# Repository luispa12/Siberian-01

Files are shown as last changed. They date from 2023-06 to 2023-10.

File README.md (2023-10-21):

test

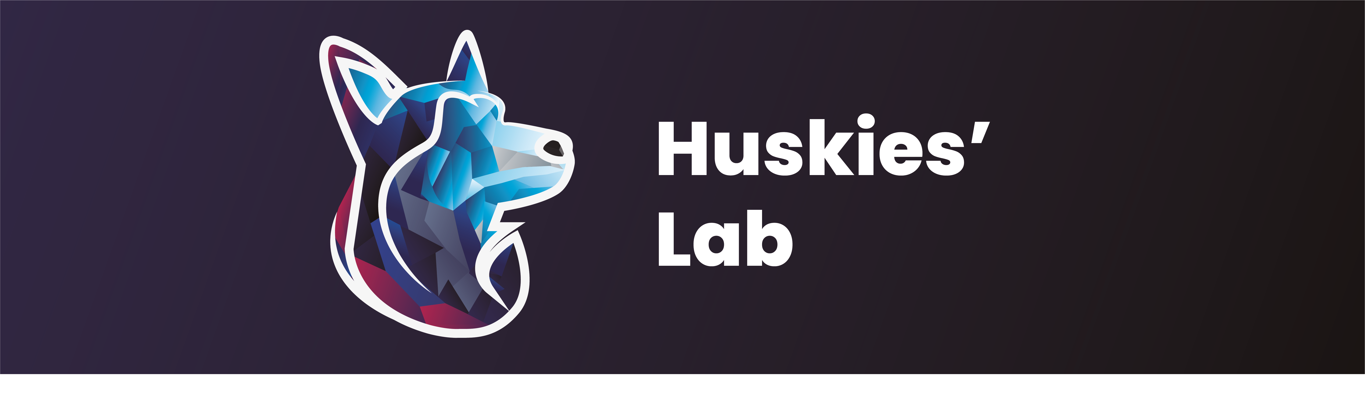
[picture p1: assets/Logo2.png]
Huskies' lab


## Project Specification

[Link to the Github repository](https://github.com/luispa12/Siberian-01)

This board is based on the RP2040 microcontroller from the Raspberry Foundation. 

It is a development board with the minimun requirements for the RP2040 IC to properly works, it complies with the USB 2.0 protocol, full use of all the GPIO pins, on board linear regulator for the 3.3V, 1 led status and another led connected to pin GPIO17.

It was designed with the purpose to learn how to design, assemble, document and manufacture (JLCPCB) printed circuit boarda (PCB's).   

### SoC Features

* Dual ARM Cortex-M0+ @ 133MHz
* 264kB on-chip SRAM in six independent banks
* Support for up to 16MB of off-chip Flash memory via dedicated QSPI bus
* DMA controller
* Fully-connected AHB crossbar
* Interpolator and integer divider peripherals
* On-chip programmable LDO to generate core voltage
* 2 on-chip PLLs to generate USB and core clocks
* 30 GPIO pins, 4 of which can be used as analog inputs
* Peripherals:
   * 2 UARTs
   * 2 SPI controllers
   * 2 I2C controllers
   * 16 PWM channels
   * USB 1.1 controller and PHY, with host and device support
   * 8 PIO state machines

For the complete description of the microcontroller, see the [RP2040 DATASHEET](https://datasheets.raspberrypi.com/rp2040/rp2040-datasheet.pdf).

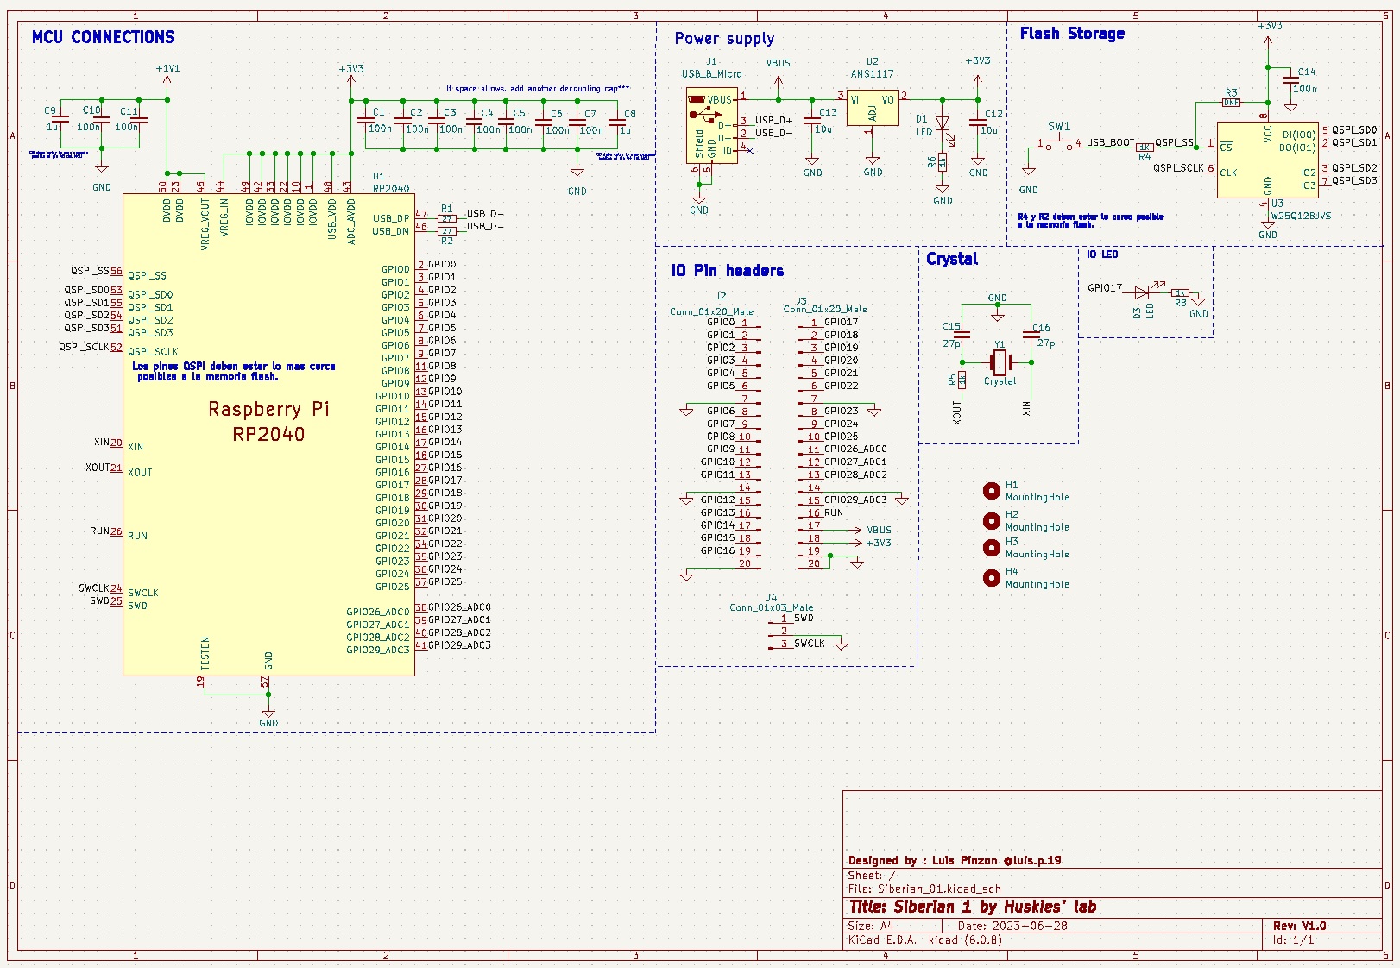
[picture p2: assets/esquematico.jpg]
Diagram


### Power

* USB Type B

#### Debug Pinout Connection 

| Pin number | SoC | Description |
|---|---|--- |
| 1 | 25 | SWD |
| 2 | -- | GND |
| 3 | 24 | SWCLK |

### Pin Layout

Pin Layou pending...

#### Left Side

| Pin number | SoC | Description |
|---|---|--- |
| 1 | 2 | GPIO0, SPI0 RX, UART0 TX, I2C0 SDA. |
| 2 | 3 | GPIO1, SPI0 CSn, UART0 RX, I2C0 SCL. |
| 3 | 4 | GPIO2, SPI0 SCK, UART0 CTS, I2C1 SDA. |
| 4 | 5 | GPIO3, SPI0 TX, UART0 RTS, I2C1 SCL. |
| 5 | 6 | GPIO4, SPI0 RX, UART1 TX, I2C0 SDA. |
| 6 | 7 | GPIO5, SPI0 CSn, UART1 RX, I2C0 SCL. |
| 7 | -- | GND. |
| 8 | 8 | GPIO6, SPI0 SCK, UART1 CTS, I2C1 SDA. |
| 9 | 9 | GPIO7, SPI0 TX, UART1 RTS, I2C1 SCL. |
| 10 | 11 | GPIO8, SPI1 RX, UART1 TX, I2C0 SDA. |
| 11 | 12 | GPIO9, SPI1 CSn, UART1 RX, I2C0 SCL. |
| 12 | 13 | GPIO10, SPI1 SCK UART1 CTS I2C1 SDA. |
| 13 | 14 | GPIO11, SPI1 TX UART1 RTS I2C1 SCL. |
| 14 | -- | GND. |
| 15 | 15 | GPIO12, SPI1 RX, UART0 TX, I2C0 SDA. |
| 16 | 16 | GPIO13, SPI1 CSn, UART0 RX, I2C0 SCL. |
| 17 | 17 | GPIO14, SPI1 SCK, UART0 CTS, I2C1 SDA. |
| 18 | 18 | GPIO15, SPI1 TX, UART0 RTS, I2C1 SCL. |
| 19 | 27 | GPIO16, SPI0 RX, UART0 TX, I2C0 SDA. |
| 20 | -- | GND. |

#### Right Side

| Pin number | SoC | Description |
|---|---|--- |
| 21 | 28 | GPIO17, SPI0 CSn, UART0 RX, I2C0 SCL. |
| 22 | 29 | GPIO18, SPI0 SCK, UART0 CTS, I2C1 SDA. |
| 23 | 30 | GPIO19, SPI0 TX, UART0 RTS, I2C1 SCL. |
| 24 | 31 | GPIO20, SPI0 RX, UART1 TX, I2C0 SDA, CLOCK GPIN0.  |
| 25 | 32 | GPIO21, SPI0 CSn, UART1 RX, I2C0 SCL, CLOCK GPOUT0.|
| 26 | 34 | GPIO22, SPI0 SCK, UART1 CTS, I2C1 SDA,CLOCK GPIN1. |
| 27 | -- | GND. |
| 28 | 35 | GPIO23, SPI0 TX, UART1 RTS, I2C1 SCL, CLOCK GPOUT1.|
| 29 | 36 | GPIO24, SPI1 RX, UART1 TX, I2C0 SDA,  CLOCK GPOUT2.|
| 30 | 36 | GPIO25, SPI1 CSn, UART1 RX, I2C0 SCL, CLOCK GPOUT3.|
| 31 | 38 | GPIO26\_ADC0, SPI1 SCK, UART1 CTS, I2C1 SDA. |
| 32 | 39 | GPIO27\_ADC1, SPI1 TX, UART1 RTS, I2C1 SCL. |
| 33 | 40 | GPIO28\_ADC2, SPI1 RX, UART0 TX, I2C0 SDA. |
| 34 | -- | GND. |
| 35 | 41 | GPIO29\_ADC3,SPI1 CSn, UART0 RX, I2C0 SCL. |
| 36 | 26 | RUN |
| 37 | -- | VBUS |
| 38 | -- | +3V3 |
| 39 | -- | GND. |
| 40 | -- | GND. |

| Function | SoC | 
|--- |--- |
| SPIx. | Connect one of the internal PL022 SPI peripherals to GPIO. | 
| UARTx. | Connect one of the internal PL011 UART peripherals to GPIO.|
| I2Cx. | Connect one of the internal DW I2C peripherals to GPIO. | 
| CLOCK GPINx. | General purpose clock inputs. Can be routed to a number of internal clock domains on RP2040, e.g. to provide a 1Hz clock for the RTC, or can be connected to an internal frequency counter.  | 
| CLOCK GPOUTx.| General purpose clock outputs. Can drive a number of internal clocks (including PLLoutputs) onto GPIOs, with optional integer divide.|

## Board Design

Top

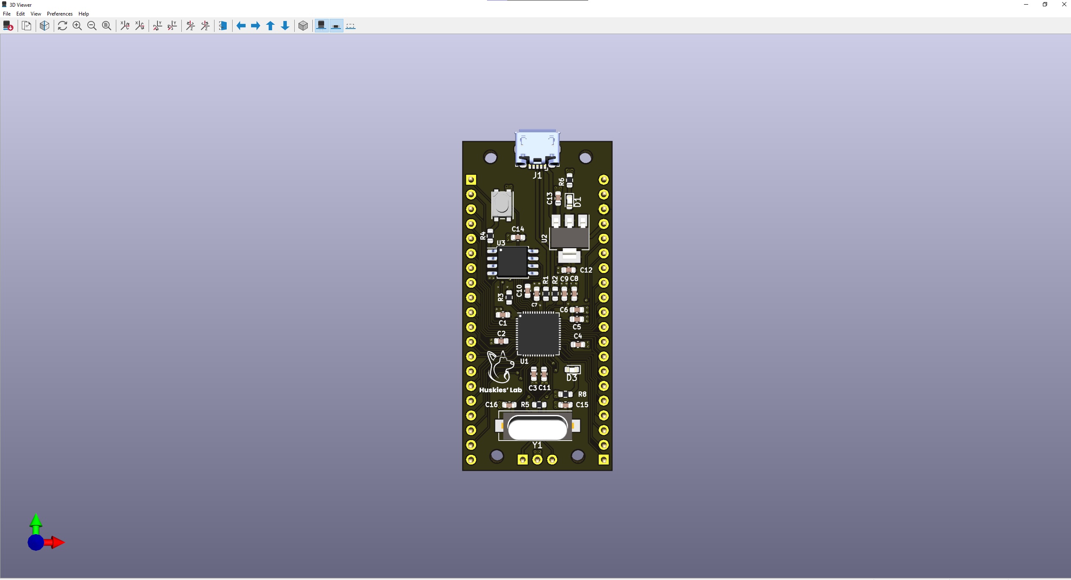
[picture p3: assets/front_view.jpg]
TOP


Bottom

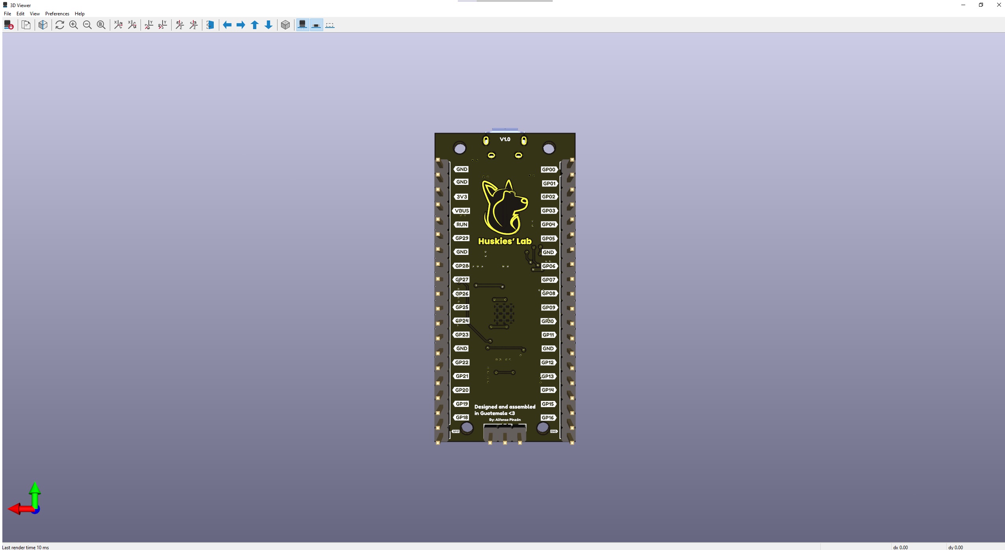
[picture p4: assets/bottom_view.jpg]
BOT


## Bill of Material

[Interactive BOM](docs/bom/bom.html)

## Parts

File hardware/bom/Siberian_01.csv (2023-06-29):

Source: | C:\Users\lapf9\OneDrive\Escritorio\huskies labs designs\Siberian_01\hardware\Siberian_01.kicad_sch
Date: | 6/28/2023 10:44:40 PM
Tool: | Eeschema (6.0.8)
Generator: | D:\kicad\6.0\bin\scripting\plugins/bom_csv_grouped_by_value_with_fp.py
Component Count: | 38
Ref | Qnty | Value | Cmp name | Footprint | Description | Vendor
C1, C2, C3, C4, C5, C6, C7, C10, C11, C14, | 10 | 100n | C_Small | Capacitor_SMD:C_0603_1608Metric | Unpolarized capacitor, small symbol
C8, C9, | 2 | 1u | C_Small | Capacitor_SMD:C_0603_1608Metric | Unpolarized capacitor, small symbol
C12, C13, | 2 | 10u | C_Small | Capacitor_SMD:C_0603_1608Metric | Unpolarized capacitor, small symbol
C15, C16, | 2 | 27p | C_Small | Capacitor_SMD:C_0603_1608Metric | Unpolarized capacitor, small symbol
D1, D3, | 2 | LED | LED | LED_SMD:LED_0603_1608Metric | Light emitting diode
H1, H2, H3, H4, | 4 | MountingHole | MountingHole | MountingHole:MountingHole_2.1mm | Mounting Hole without connection
J1, | 1 | USB_B_Micro | USB_B_Micro | Connector_USB:USB_Micro-B_Amphenol_10118194_Horizontal | USB Micro Type B connector
J2, J3, | 2 | Conn_01x20_Male | Conn_01x20_Male | Connector_PinHeader_2.54mm:PinHeader_1x20_P2.54mm_Vertical | Generic connector, single row, 01x20, script generated (kicad-library-utils/schlib/autogen/connector/)
J4, | 1 | Conn_01x03_Male | Conn_01x03_Male | Connector_PinHeader_2.54mm:PinHeader_1x03_P2.54mm_Vertical | Generic connector, single row, 01x03, script generated (kicad-library-utils/schlib/autogen/connector/)
R1, | 1 | 27 | R_Small | Resistor_SMD:R_0603_1608Metric | Resistor, small symbol
R2, | 1 | 27 | R_Small | Resistor_SMD:R_0603_1608Metric | Resistor, small symbol
R3, | 1 | DNF | R_Small | Resistor_SMD:R_0603_1608Metric | Resistor, small symbol
R4, | 1 | 1K | R_Small | Resistor_SMD:R_0603_1608Metric | Resistor, small symbol
R5, R6, R8, | 3 | 1k | R_Small | Resistor_SMD:R_0603_1608Metric | Resistor, small symbol
SW1, | 1 | PTS815_SJM_250_SMTR_LFS | PTS815_SJM_250_SMTR_LFS | FOOTPRINTS_s1:SW4_PTS815 SJM 250 SMTR LFS_CNK
U1, | 1 | RP2040 | RP2040 | MCU_RaspberryPi_and_Boards:RP2040-QFN-56
U2, | 1 | AMS1117 | AMS1117 | Package_TO_SOT_SMD:SOT-223-3_TabPin2 | 1A Low Dropout regulator, positive, adjustable output, SOT-223
U3, | 1 | W25Q128JVS | W25Q128JVS | Package_SO:SOIC-8_5.23x5.23mm_P1.27mm | 128Mb Serial Flash Memory, Standard/Dual/Quad SPI, SOIC-8
Y1, | 1 | Crystal | Crystal | MCU_RaspberryPi_and_Boards:Crystal_SMD_HC49-US | Two pin crystal

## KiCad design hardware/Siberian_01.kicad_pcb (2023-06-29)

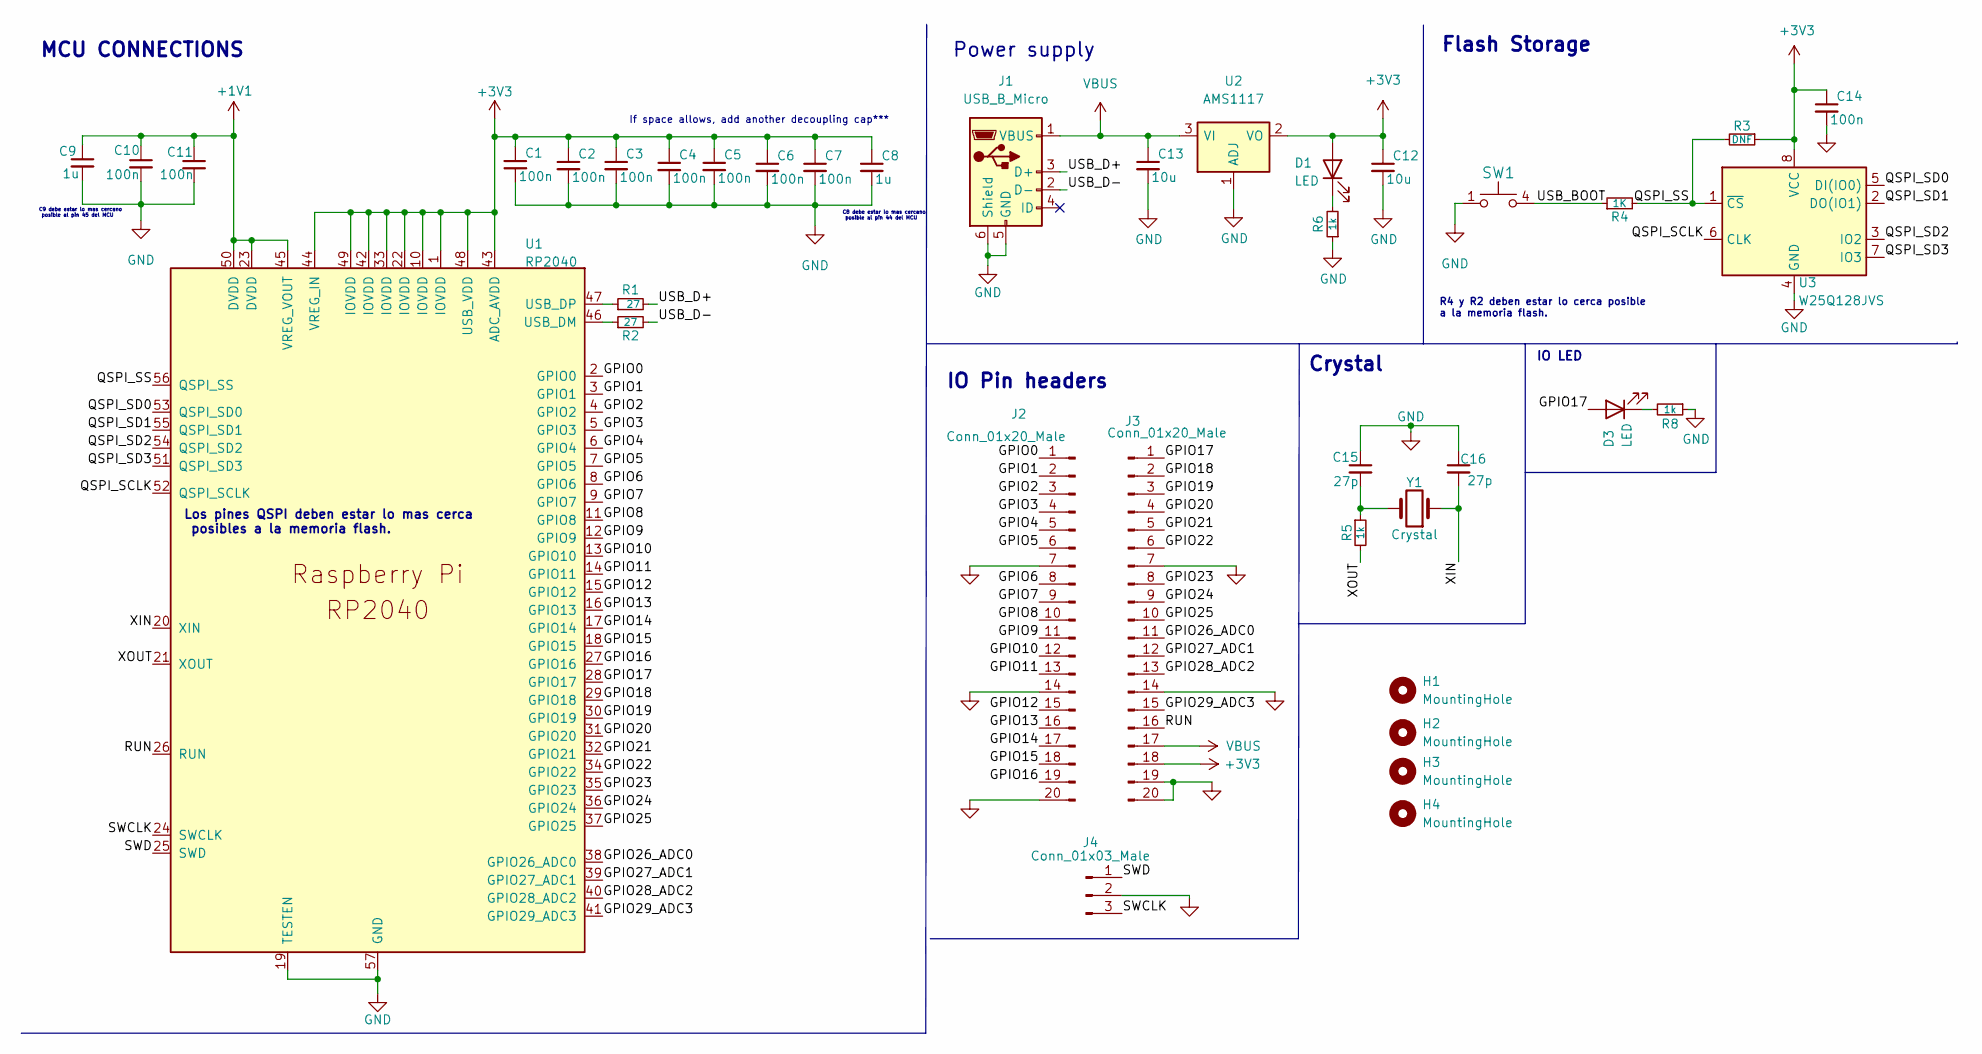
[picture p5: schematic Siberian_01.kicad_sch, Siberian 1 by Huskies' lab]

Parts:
C1, C2, C3, C4, C5, C6, C7, C10, C11, C14: 100n; C_0603_1608Metric
C8, C9: 1u; C_0603_1608Metric
C12, C13: 10u; C_0603_1608Metric
C15, C16: 27p; C_0603_1608Metric
D1, D3: LED; LED_0603_1608Metric
H1, H2, H3, H4: MountingHole; MountingHole_2.1mm
J1: USB_B_Micro; USB_Micro-B_Amphenol_10118194_Horizontal
J2, J3: Conn_01x20_Male; PinHeader_1x20_P2.54mm_Vertical
J4: Conn_01x03_Male; PinHeader_1x03_P2.54mm_Vertical
R1, R2: 27; R_0603_1608Metric
R3: DNF; R_0603_1608Metric
R4: 1K; R_0603_1608Metric
R5, R6, R8: 1k; R_0603_1608Metric
SW1: PTS815_SJM_250_SMTR_LFS; SW4_PTS815 SJM 250 SMTR LFS_CNK
U1: RP2040; RP2040-QFN-56
U2: AMS1117; SOT-223-3_TabPin2
U3: W25Q128JVS; SOIC-8_5.23x5.23mm_P1.27mm
Y1: Crystal; Crystal_SMD_HC49-US

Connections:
+1V1: C9.1, C10.1, C11.1, U1.23 (DVDD), U1.45 (VREG_VOUT), U1.50 (DVDD)
+3V3: C1.1, C2.1, C3.1, C4.1, C5.1, C6.1, C7.1, C8.1, C12.1, C14.1, D1.2 (A), J3.18, R3.1, U1.1 (IOVDD), U1.10 (IOVDD), U1.22 (IOVDD), U1.33 (IOVDD), U1.42 (IOVDD), U1.43 (ADC_AVDD), U1.44 (VREG_IN), U1.48 (USB_VDD), U1.49 (IOVDD), U2.2 (VO), U3.8 (VCC)
/GPIO0: J2.1, U1.2 (GPIO0)
/GPIO1: J2.2, U1.3 (GPIO1)
/GPIO2: J2.3, U1.4 (GPIO2)
/GPIO3: J2.4, U1.5 (GPIO3)
/GPIO4: J2.5, U1.6 (GPIO4)
/GPIO5: J2.6, U1.7 (GPIO5)
/GPIO6: J2.8, U1.8 (GPIO6)
/GPIO7: J2.9, U1.9 (GPIO7)
/GPIO8: J2.10, U1.11 (GPIO8)
/GPIO9: J2.11, U1.12 (GPIO9)
/GPIO10: J2.12, U1.13 (GPIO10)
/GPIO11: J2.13, U1.14 (GPIO11)
/GPIO12: J2.15, U1.15 (GPIO12)
/GPIO13: J2.16, U1.16 (GPIO13)
/GPIO14: J2.17, U1.17 (GPIO14)
/GPIO15: J2.18, U1.18 (GPIO15)
/GPIO16: J2.19, U1.27 (GPIO16)
/GPIO17: D3.2 (A), J3.1, U1.28 (GPIO17)
/GPIO18: J3.2, U1.29 (GPIO18)
/GPIO19: J3.3, U1.30 (GPIO19)
/GPIO20: J3.4, U1.31 (GPIO20)
/GPIO21: J3.5, U1.32 (GPIO21)
/GPIO22: J3.6, U1.34 (GPIO22)
/GPIO23: J3.8, U1.35 (GPIO23)
/GPIO24: J3.9, U1.36 (GPIO24)
/GPIO25: J3.10, U1.37 (GPIO25)
/GPIO26_ADC0: J3.11, U1.38 (GPIO26_ADC0)
/GPIO27_ADC1: J3.12, U1.39 (GPIO27_ADC1)
/GPIO28_ADC2: J3.13, U1.40 (GPIO28_ADC2)
/GPIO29_ADC3: J3.15, U1.41 (GPIO29_ADC3)
/QSPI_SCLK: U1.52 (QSPI_SCLK), U3.6 (CLK)
/QSPI_SD0: U1.53 (QSPI_SD0), U3.5 (DI(IO0))
/QSPI_SD1: U1.55 (QSPI_SD1), U3.2 (DO(IO1))
/QSPI_SD2: U1.54 (QSPI_SD2), U3.3 (IO2)
/QSPI_SD3: U1.51 (QSPI_SD3), U3.7 (IO3)
/QSPI_SS: R3.2, R4.2, U1.56 (QSPI_SS), U3.1 (~CS)
/RUN: J3.16, U1.26 (RUN)
/SWCLK: J4.3, U1.24 (SWCLK)
/SWD: J4.1, U1.25 (SWD)
/USB_BOOT: R4.1, SW1.4
/USB_D+: J1.3 (D+), R1.2
/USB_D-: J1.2 (D-), R2.2
/XIN: C16.2, U1.20 (XIN), Y1.1
/XOUT: R5.2, U1.21 (XOUT)
GND: C1.2, C2.2, C3.2, C4.2, C5.2, C6.2, C7.2, C8.2, C9.2, C10.2, C11.2, C12.2, C13.2, C14.2, C15.1, C16.1, J1.5 (GND), J1.6 (Shield), J2.7, J2.14, J2.20, J3.7, J3.14, J3.19, J3.20, J4.2, R6.1, R8.1, SW1.1, U1.19 (TESTEN), U1.57 (GND), U2.1 (ADJ), U3.4 (GND)
unnamed: C15.2, R5.1, Y1.2
unnamed: D1.1 (K), R6.2
unnamed: D3.1 (K), R8.2
unnamed: R1.1, U1.47 (USB_DP)
unnamed: R2.1, U1.46 (USB_DM)
VBUS: C13.1, J1.1 (VBUS), J3.17, U2.3 (VI)

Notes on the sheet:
Los pines QSPI deben estar lo mas cerca posibles a la memoria flash.
MCU CONNECTIONS
C8 debe estar lo mas cercano posible al pin 44 del MCU
R4 y R2 deben estar lo cerca posible a la memoria flash.
If space allows, add another decoupling cap***
Power supply
IO LED
C9 debe estar lo mas cercano posible al pin 45 del MCU
IO Pin headers
Flash Storage
Crystal

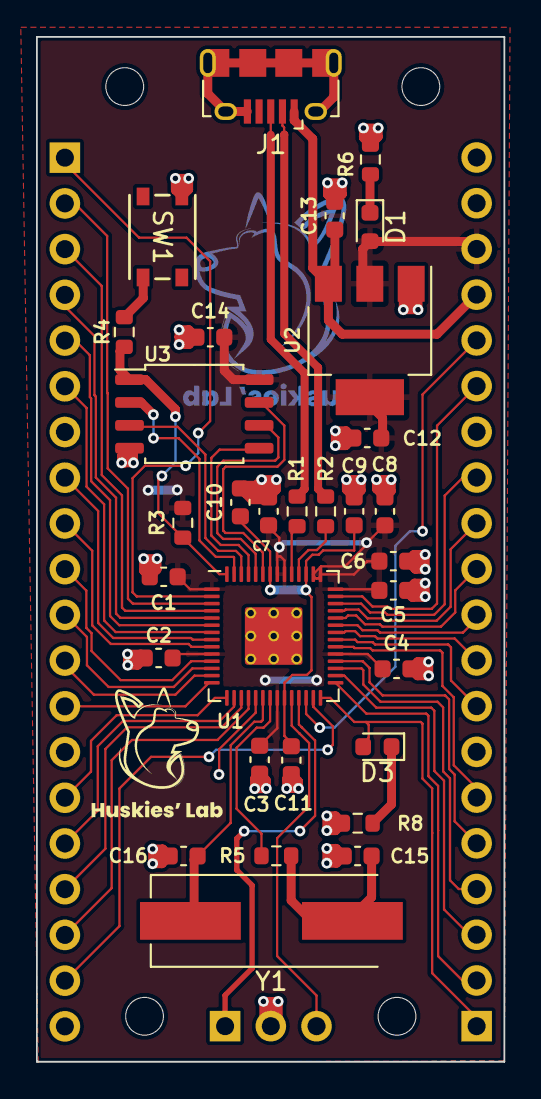
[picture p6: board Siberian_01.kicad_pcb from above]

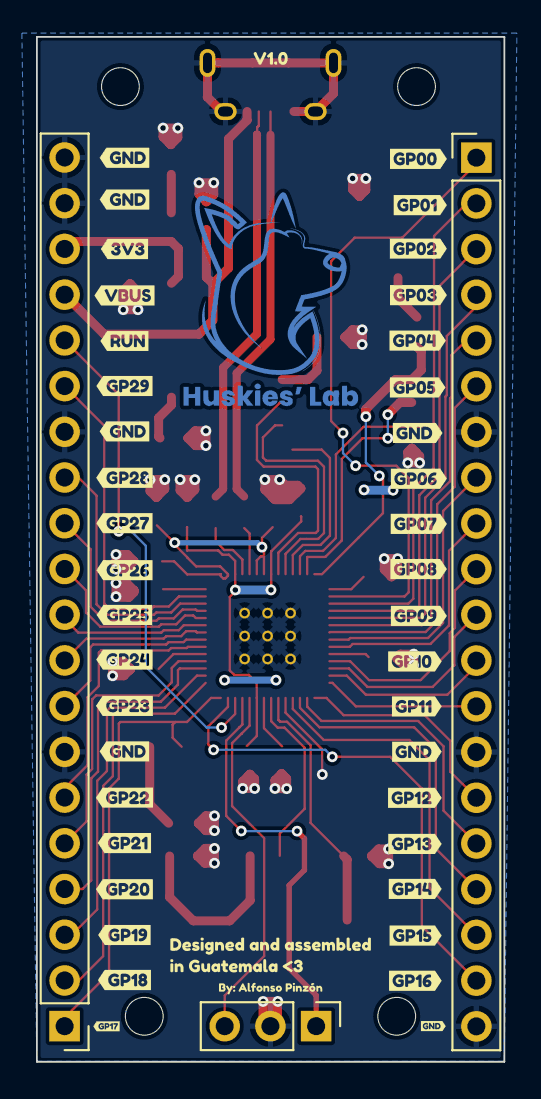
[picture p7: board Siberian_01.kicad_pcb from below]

Board: 2 copper layers, 26.0 x 56.9 mm, 81 parts (46 on the bottom side), 53 nets.

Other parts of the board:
kibuzzard-648F2C57: G***; kibuzzard-648F2C57
kibuzzard-648F2C96, kibuzzard-648F2C96#2, kibuzzard-648F2C96#3: G***; kibuzzard-648F2C96
kibuzzard-648F2CA2: G***; kibuzzard-648F2CA2
kibuzzard-648F2CB5: G***; kibuzzard-648F2CB5
kibuzzard-648F2CBD: G***; kibuzzard-648F2CBD
kibuzzard-648F2CC6: G***; kibuzzard-648F2CC6
kibuzzard-648F2CDB: G***; kibuzzard-648F2CDB
kibuzzard-648F2CE5: G***; kibuzzard-648F2CE5
kibuzzard-648F2D0C: G***; kibuzzard-648F2D0C
kibuzzard-648F2D2B: G***; kibuzzard-648F2D2B
kibuzzard-648F2D4D: G***; kibuzzard-648F2D4D
kibuzzard-648F2D5B: G***; kibuzzard-648F2D5B
kibuzzard-648F2D6A: G***; kibuzzard-648F2D6A
kibuzzard-648F2D18: G***; kibuzzard-648F2D18
kibuzzard-648F2D22: G***; kibuzzard-648F2D22
kibuzzard-648F2D43: G***; kibuzzard-648F2D43
kibuzzard-648F2D75: G***; kibuzzard-648F2D75
kibuzzard-648F36A4: G***; kibuzzard-648F36A4
kibuzzard-648F36AB: G***; kibuzzard-648F36AB
kibuzzard-648F36B6: G***; kibuzzard-648F36B6
kibuzzard-648F36C6: G***; kibuzzard-648F36C6
kibuzzard-648F38C2: G***; kibuzzard-648F38C2
kibuzzard-648F368A: G***; kibuzzard-648F368A
kibuzzard-648F369C: G***; kibuzzard-648F369C
kibuzzard-648F3652: G***; kibuzzard-648F3652
kibuzzard-648F3680: G***; kibuzzard-648F3680
kibuzzard-648F3832: G***; kibuzzard-648F3832
kibuzzard-648FA7D0: G***; kibuzzard-648FA7D0
kibuzzard-648FAA0F: G***; kibuzzard-648FAA0F
kibuzzard-649102A3: G***; kibuzzard-649102A3
kibuzzard-649102AA: G***; kibuzzard-649102AA
kibuzzard-649102B0: G***; kibuzzard-649102B0
kibuzzard-649102B6: G***; kibuzzard-649102B6
kibuzzard-649102CC: G***; kibuzzard-649102CC
kibuzzard-649102D1: G***; kibuzzard-649102D1
kibuzzard-649102D9: G***; kibuzzard-649102D9
kibuzzard-649102E1: G***; kibuzzard-649102E1
kibuzzard-649125AB: G***; kibuzzard-649125AB
kibuzzard-6491029F: G***; kibuzzard-6491029F
kibuzzard-64910299: G***; kibuzzard-64910299
kibuzzard-64910390: G***; kibuzzard-64910390

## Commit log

2023-06-29 modification to files to have it more organized
    [Siberian_01.kicad_pcb, Siberian_01.kicad_sch]
2023-06-29 added the interactive bom and bom.cvs
    [RP2040_devBoard-B_Cu.gbl, RP2040_devBoard-B_Mask.gbs, RP2040_devBoard-B_Paste.gbp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]
2023-06-29 interactive bom
2023-06-29 Rename index.html to bom.html
    change the name of the file
2023-06-30 added the interactie on the same repo and added the librarios for the switch
2023-07-03 README: added the pin description, and also a brief description of the project.
